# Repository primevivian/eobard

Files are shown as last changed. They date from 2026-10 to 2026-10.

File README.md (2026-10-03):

# Meet Eobard, a split 34 key ortholinear keyboard.
Current Hardware Revision: 1.0

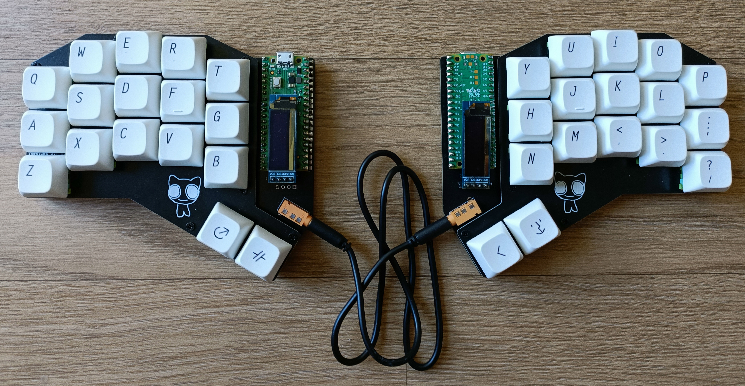
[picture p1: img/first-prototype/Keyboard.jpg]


## Project Description
Eobard is an ortholinear 34 key split keyboard made for my personal needs. Inspired by the [Ferris](https://github.com/pierrechevalier83/ferris).

The columns are spaced out vertically so as to provide the most comfortable typing experience for my hand size. It is designed to be cheap to manufacture and simple to assemble. The single PCB is dual sided, only having to be flipped around for assembly of the other side.

<details>
<summary>Project Tasks</summary>

- [x] Update files to KiCad 10.0.
- [x] Update footprints to comply with more standard libraries and parts. 
- [x] Simplify design as much as possible.
- [ ] Build diodeless prototype.
- [ ] Write Firmware in C.
- [ ] Release First Version.
</details>

## Bill of Materials 
* Raspberry Pi Pico [x2]
* [PJ-320A 3.5mm Audio Jack [x2]](https://www.lcsc.com/product-detail/Audio-Connectors_Hong-Cheng-HC-PJ-320A_C7501806.html)
* Cherry MX Style Switches [x34]
* 4mm M2 Standoff [x9]
* 3mm M2 Screws [x18]
* 01x20 2.54mm Standard Male Pin Headers [x4] [If Pico doesn't have them pre-soldered]

## Ordering PCBs
Dragging and dropping the provided Gerber zips onto JLCPCB or other manufacturer's websites should work just fine. Make sure the plate PCB is 1mm thick and the main pcb is 1.6mm thick.

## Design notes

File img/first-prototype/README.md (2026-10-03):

## Images (First Prototype)
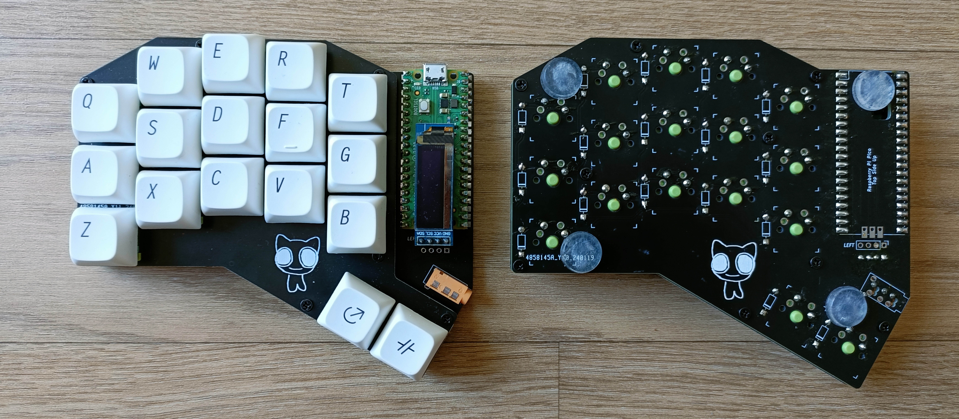
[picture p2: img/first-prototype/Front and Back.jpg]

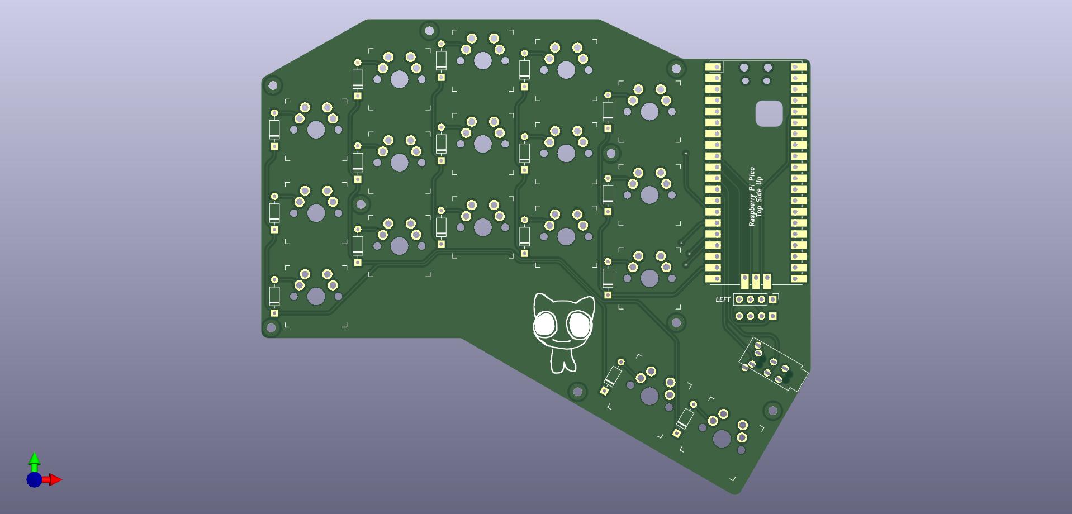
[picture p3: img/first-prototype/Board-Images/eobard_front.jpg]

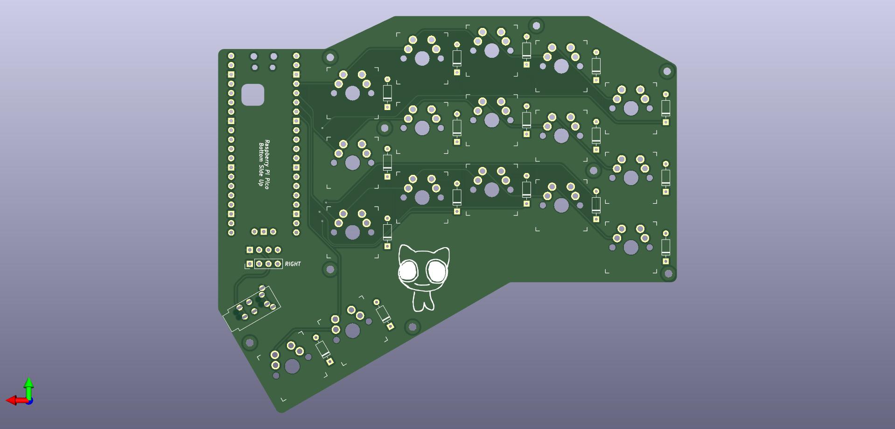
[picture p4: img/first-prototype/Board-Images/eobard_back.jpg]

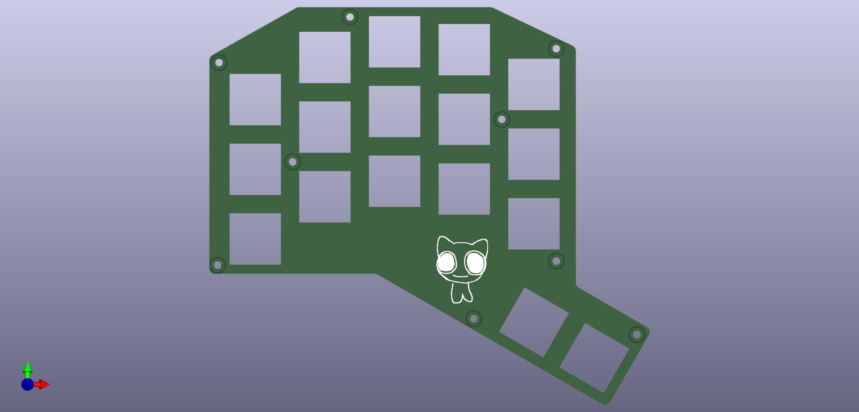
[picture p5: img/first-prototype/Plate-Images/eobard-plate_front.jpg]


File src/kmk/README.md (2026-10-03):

# Eobard Firmware
(DEPRECATED)
The first prototype used KMK firmware as a base. Follow their (Getting Started Guide)[https://github.com/KMKfw/kmk_firmware/blob/master/docs/en/Getting_Started.md] to properly setup both sides.
This firmware needs to be flashed into both sides.

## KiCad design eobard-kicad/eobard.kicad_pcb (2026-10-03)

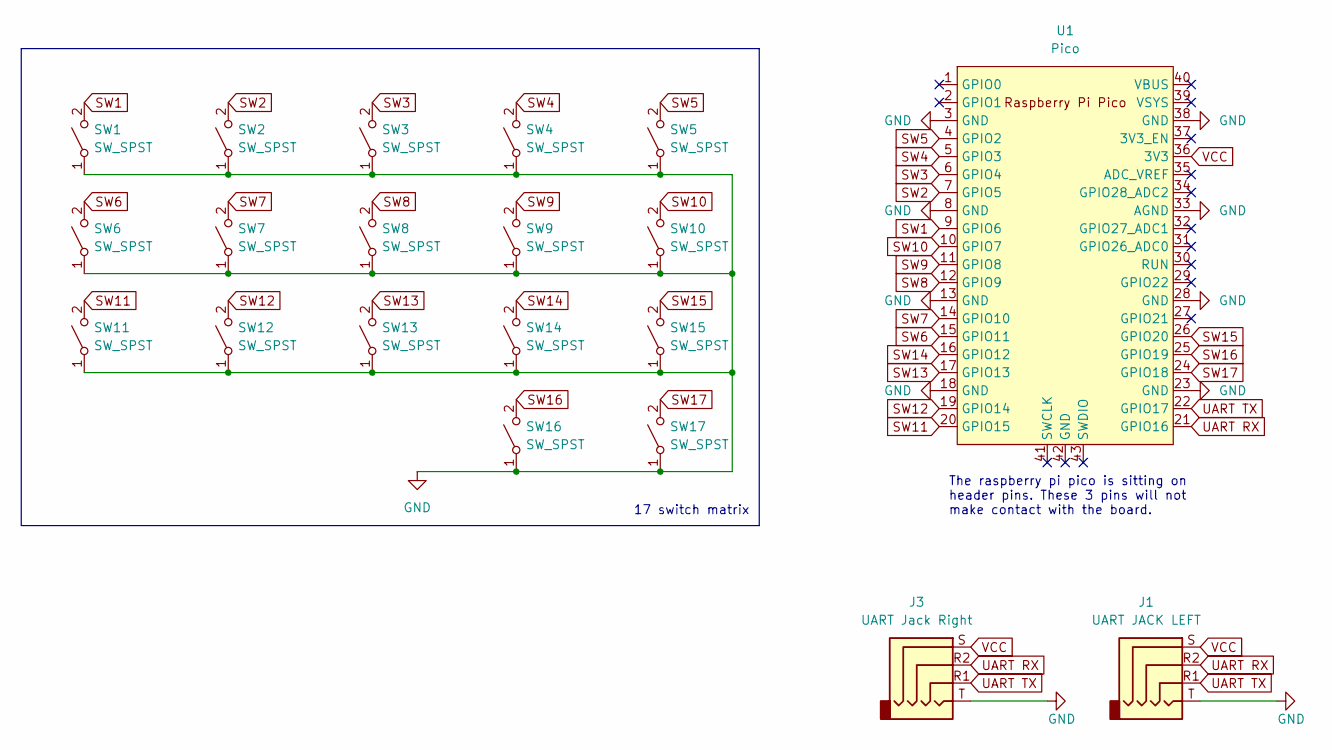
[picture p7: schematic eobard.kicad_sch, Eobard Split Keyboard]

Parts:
J1: UART JACK LEFT; PJ-320A
J3: UART Jack Right; PJ-320A
SW1, SW2, SW3, SW4, SW5, SW6, SW7, SW8, SW9, SW10, SW11, SW12, SW13, SW14, SW15, SW16, SW17: SW_SPST; SW_MX_reversible
U1: Pico; RPi_Pico_SMD_TH

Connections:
GND: J1.T, J3.T, SW1.1 (A), SW2.1 (A), SW3.1 (A), SW4.1 (A), SW5.1 (A), SW6.1 (A), SW7.1 (A), SW8.1 (A), SW9.1 (A), SW10.1 (A), SW11.1 (A), SW12.1 (A), SW13.1 (A), SW14.1 (A), SW15.1 (A), SW16.1 (A), SW17.1 (A), U1.3 (GND), U1.8 (GND), U1.13 (GND), U1.18 (GND), U1.23 (GND), U1.28 (GND), U1.33 (AGND), U1.38 (GND)
SW1: SW1.2 (B), U1.9 (GPIO6)
SW2: SW2.2 (B), U1.7 (GPIO5)
SW3: SW3.2 (B), U1.6 (GPIO4)
SW4: SW4.2 (B), U1.5 (GPIO3)
SW5: SW5.2 (B), U1.4 (GPIO2)
SW6: SW6.2 (B), U1.15 (GPIO11)
SW7: SW7.2 (B), U1.14 (GPIO10)
SW8: SW8.2 (B), U1.12 (GPIO9)
SW9: SW9.2 (B), U1.11 (GPIO8)
SW10: SW10.2 (B), U1.10 (GPIO7)
SW11: SW11.2 (B), U1.20 (GPIO15)
SW12: SW12.2 (B), U1.19 (GPIO14)
SW13: SW13.2 (B), U1.17 (GPIO13)
SW14: SW14.2 (B), U1.16 (GPIO12)
SW15: SW15.2 (B), U1.26 (GPIO20)
SW16: SW16.2 (B), U1.25 (GPIO19)
SW17: SW17.2 (B), U1.24 (GPIO18)
UART RX: J1.R2, J3.R2, U1.21 (GPIO16)
UART TX: J1.R1, J3.R1, U1.22 (GPIO17)
VCC: J1.S, J3.S, U1.36 (3V3)

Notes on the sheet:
The raspberry pi pico is sitting on header pins. These 3 pins will not make contact with the board.
17 switch matrix

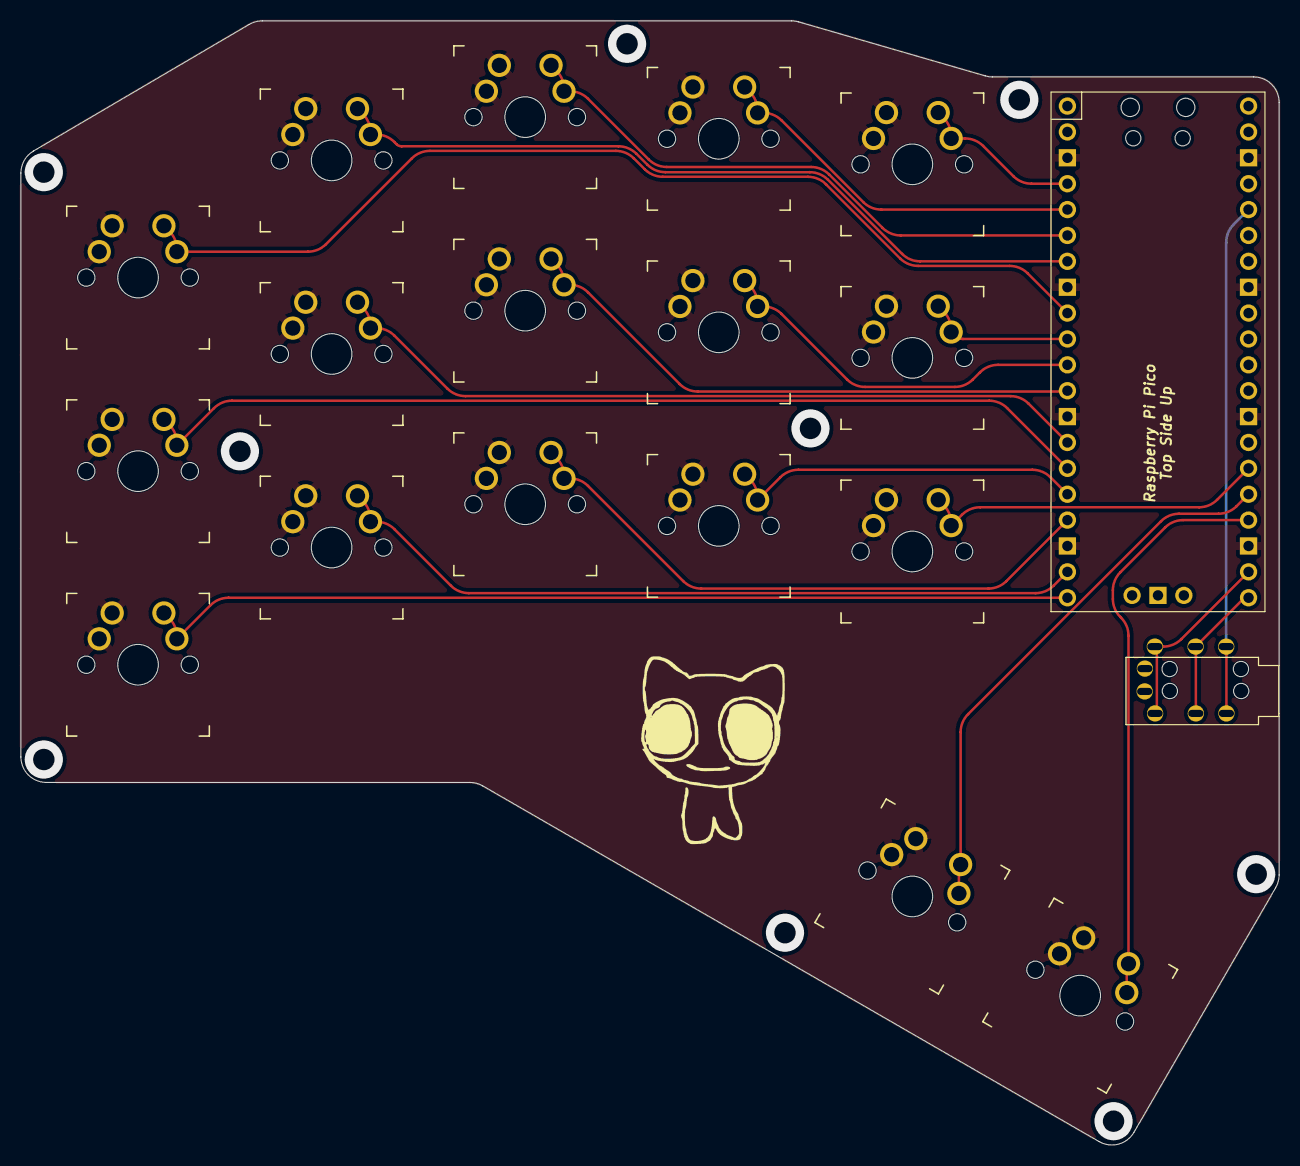
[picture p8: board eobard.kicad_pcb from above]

Board: 2 copper layers, 123.5 x 110.3 mm, 20 parts (1 on the bottom side), 21 nets.

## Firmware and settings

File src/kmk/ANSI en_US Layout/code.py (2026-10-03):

# ███████  ██████  ██████   █████  ██████  ██████      ███████ ██     ██ 
# ██      ██    ██ ██   ██ ██   ██ ██   ██ ██   ██     ██      ██     ██ 
# █████   ██    ██ ██████  ███████ ██████  ██   ██     █████   ██  █  ██ 
# ██      ██    ██ ██   ██ ██   ██ ██   ██ ██   ██     ██      ██ ███ ██ 
# ███████  ██████  ██████  ██   ██ ██   ██ ██████      ██       ███ ███  
#                         
## Written by primevivian, 2024
## en_US Layout

print("Starting")
import board

from kmk.kmk_keyboard import KMKKeyboard
from kmk.keys import KC
from kmk.scanners import DiodeOrientation
from kmk.modules.split import Split, SplitType
from kmk.modules.layers import Layers

keyboard = KMKKeyboard()
keyboard.debug_enabled = True

### Keyboard Modules
split = Split(split_type=SplitType.UART, split_side=None, data_pin=board.GP9, data_pin2=board.GP8, uart_flip=True, use_pio=True)
keyboard.modules.append(split)
layers = Layers()
keyboard.modules.append(layers)

### Key Matrix and Diodes
keyboard.col_pins = (board.GP10,board.GP11,board.GP12,board.GP13,board.GP14) 
keyboard.row_pins = (board.GP2,board.GP3,board.GP4,board.GP5)
keyboard.diode_orientation = DiodeOrientation.ROW2COL

### Cleanup naming scheme
_______ = KC.TRNS
XXXXXXX = KC.NO

### Home Row Layer Taps
S_L2 = KC.LT(2, KC.S)
D_L1 = KC.LT(1, KC.D)
F_L4 = KC.LT(4, KC.F)
J_L3 = KC.LT(3, KC.J)
K_L5 = KC.LT(5, KC.K)
SPC_L6 = KC.LT(6, KC.SPC)

### Keymap
keyboard.keymap = [
    [  # 0 QWERTY LAYER
        KC.Q,    KC.W,    KC.E,    KC.R,    KC.T,    KC.Y,    KC.U,    KC.I,    KC.O,    KC.P,
        KC.A,    S_L2,    D_L1,    F_L4,    KC.G,    KC.H,    J_L3,    K_L5,    KC.L, KC.SCLN,
        KC.Z,    KC.X,    KC.C,    KC.V,    KC.B,    KC.N,    KC.M, KC.COMM,  KC.DOT, KC.SLSH,
     KC.LSFT,  SPC_L6, XXXXXXX, XXXXXXX, XXXXXXX, XXXXXXX, XXXXXXX, XXXXXXX,  KC.ENT, KC.BSPC,
    ],
    [  # 1 NAVIGATION LAYER
    _______, _______, _______, _______, _______, _______, _______, KC.PGUP, _______, _______,
    KC.PSCR, KC.LGUI, _______, KC.HYPR, _______, KC.LEFT, KC.DOWN,   KC.UP, KC.RGHT, _______,
    _______, _______, _______, _______, _______, _______, KC.HOME, KC.PGDN,  KC.END, _______,
    _______, _______, _______, _______, _______, _______, _______, _______, _______, _______,
    ],
    [  # 2 NUMPAD
    _______, _______, _______, _______, _______, KC.SLSH,   KC.N7,   KC.N8,   KC.N9, KC.MINS,
    _______, _______, _______, _______, _______, KC.ASTR,   KC.N4,   KC.N5,   KC.N6, KC.PLUS,
    _______, _______, _______, _______, _______,   KC.N0,   KC.N1,   KC.N2,   KC.N3,  KC.EQL,
    _______, _______, _______, _______, _______, _______, _______, _______, _______, _______,
    ],
    [  # 3 LEFT SYMBOLS
    _______, KC.COLN, KC.LABK, KC.RABK, KC.SCLN, _______, _______, _______, _______, _______,
    KC.LCBR, KC.RCBR, KC.LPRN, KC.RPRN,   KC.AT, _______, _______,  KC.EQL, KC.PLUS, KC.PERC,
    _______, KC.EXLM, KC.LBRC, KC.RBRC, _______, _______, _______, _______, _______, _______,
    _______, _______, _______, _______, _______, _______, _______, _______, _______, _______,
    ],
    [  # 4 RIGHT SYMBOLS
    _______, _______, _______, _______, _______, _______, KC.UNDS, KC.PIPE, KC.QUOT, _______,
    KC.CIRC, KC.ASTR, KC.AMPR, _______, _______, KC.HASH, KC.TILD, KC.SLSH, KC.DQUO,  KC.DLR,
    _______, _______, _______, _______, _______, _______, KC.MINS, KC.BSLS,  KC.GRV, _______,
    _______, _______, _______, _______, _______, _______, _______, _______, _______, _______,
    ],
    [  # 5 FUNCTION KEYS
      KC.F9,  KC.F10,  KC.F11,  KC.F12, _______, _______, _______, _______, _______, _______,
      KC.F5,   KC.F6,   KC.F7,   KC.F8, _______, _______, _______, _______, _______, _______,
      KC.F1,   KC.F2,   KC.F3,   KC.F4, _______, _______, _______, _______, _______, _______,
    _______, _______, _______, _______, _______, _______, _______, _______, _______, _______,
    ],
    [  # 6 ALWAYS AVAILABLE [THUMB QUICK ACCESS LAYER]
    _______, _______, KC.COLN,  KC.ESC, _______, _______, _______, _______, _______,  KC.DEL,
     KC.TAB, KC.PERC, KC.SLSH,  KC.ENT, _______, _______, KC.LGUI, _______, _______, _______,
    KC.CAPS, _______, _______, KC.PERC, _______, _______, KC.RALT, KC.RCTL, _______, KC.RESET,
    _______, _______, _______, _______, _______, _______, _______, _______, _______, _______,
    ],
]

if __name__ == '__main__':
    keyboard.go()

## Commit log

2024-11-07 Small Update
    Coming back to this to finally finish it :3
    [eobard.kicad_pcb, eobard.kicad_sch]
2026-10-03 Revise project updates and task list in README
    Updated project status and tasks in README.md to reflect current goals and progress.
2026-10-03 Updated KiCad files to newer version
    Updated files to KiCad 10.0.
    [eobard-B_Cu.gbl, eobard-B_Mask.gbs, eobard-B_Paste.gbp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]
2026-10-03 Files reorganized
    [eobard.kicad_pcb, eobard.kicad_sch]
2026-10-21 Firmware progress
    Currently building firmware for the old, diode based prototype to test some ideas.
2026-10-27 Diodeless Firmware Update
2026-10-27 Regenerated gerbers in KiCad 10
2026-10-28 Stop tracking editor settings and kicad backups
